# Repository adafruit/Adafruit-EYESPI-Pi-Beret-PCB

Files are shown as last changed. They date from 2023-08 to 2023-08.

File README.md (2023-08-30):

## Adafruit EYESPI Pi Beret PCB

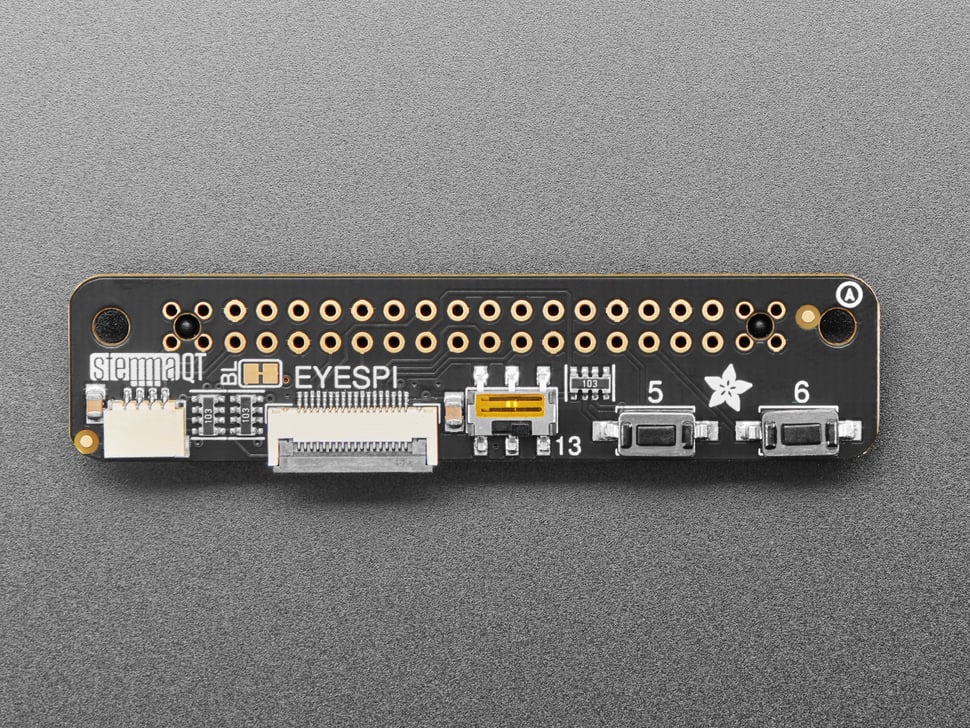
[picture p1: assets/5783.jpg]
<a href="http://www.adafruit.com/products/5783"><br/>
Click here to purchase one from the Adafruit shop</a>

PCB files for the Adafruit EYESPI Pi Beret. 

Format is EagleCAD schematic and board layout
* https://www.adafruit.com/product/5783

### Description

Raspberry Pi's make for handy lil computers, but they're really wonderful when you can connect all sorts of nifty hardware to them: color TFT or E-Ink displays, and sensors are our go-to favorites. Even better is when we make it fast and effortless to wire these up. With this new EYESPI Pi Beret there's no more counting pins or noodling with a breakout board. This slim HAT plugs in and gives you lots of hardware connection options so that many projects become plug-and-play.

Our most recent display breakouts have come with a new feature: an 18-pin "EYE SPI" standard FPC connector with flip-top connector. This is intended to be a sort-of "STEMMA QT for displays" - a way to quickly connect and extend display wiring that uses a lot of SPI pins. In this case we need a lot of SPI and accessory pins, and we want to be able to use long distances, so we go with an 18-pin 0.5mm pitch FPC.

With such a slim and flexible cable, it's easy to have displays anywhere without them physically attached to the Pi like in our PiTFTs. Accessorize with big bold colorful displays or power-sipping E-Ink. 

Don't forget you'll also want an 18-pin EYESPI FPC cable. And of course one of our EYESPI displays too - look for the EYESPI logo on the back to know you've got one that can clip in.

* MOSI/MISO/SCK SPI pins are connected to the default SPI port on the Raspberry Pi
* SDA/SCL I2C pins are connected to the default I2C port on the Pi
* Display CS on Raspberry Pi CE 0
* Display DC on Raspberry Pi GPIO #25
* Display Reset on Raspberry Pi GPIO #27
* Display Busy on Raspberry Pi GPIO #17 (used for E-Inks)
* Display Backlight on Raspberry Pi GPIO #18 (there's a jumper to cut/disable this if you want to use the PWM output for other uses like NeoPixels)
* Touch CS on Raspberry Pi CE 1
* Touch IRQ on Raspberry Pi GPIO #24

The remaining EYESPI pins are not connected, leaving you with plenty of GPIO for other accessory boards.

We also have a Stemma QT connector for the I2C port, to make connecting all sorts of Qwiic/Stemma QT devices super easy, two tactile switches on GPIO #5 and #6 and a slide switch on GPIO #13 which you can use for any sort of interface project or configuration.

Display and EYESPI cable are not included.

### License

Adafruit invests time and resources providing this open source design, please support Adafruit and open-source hardware by purchasing products from [Adafruit](https://www.adafruit.com)!

Designed by Limor Fried/Ladyada for Adafruit Industries.

Creative Commons Attribution/Share-Alike, all text above must be included in any redistribution. 
See license.txt for additional details.

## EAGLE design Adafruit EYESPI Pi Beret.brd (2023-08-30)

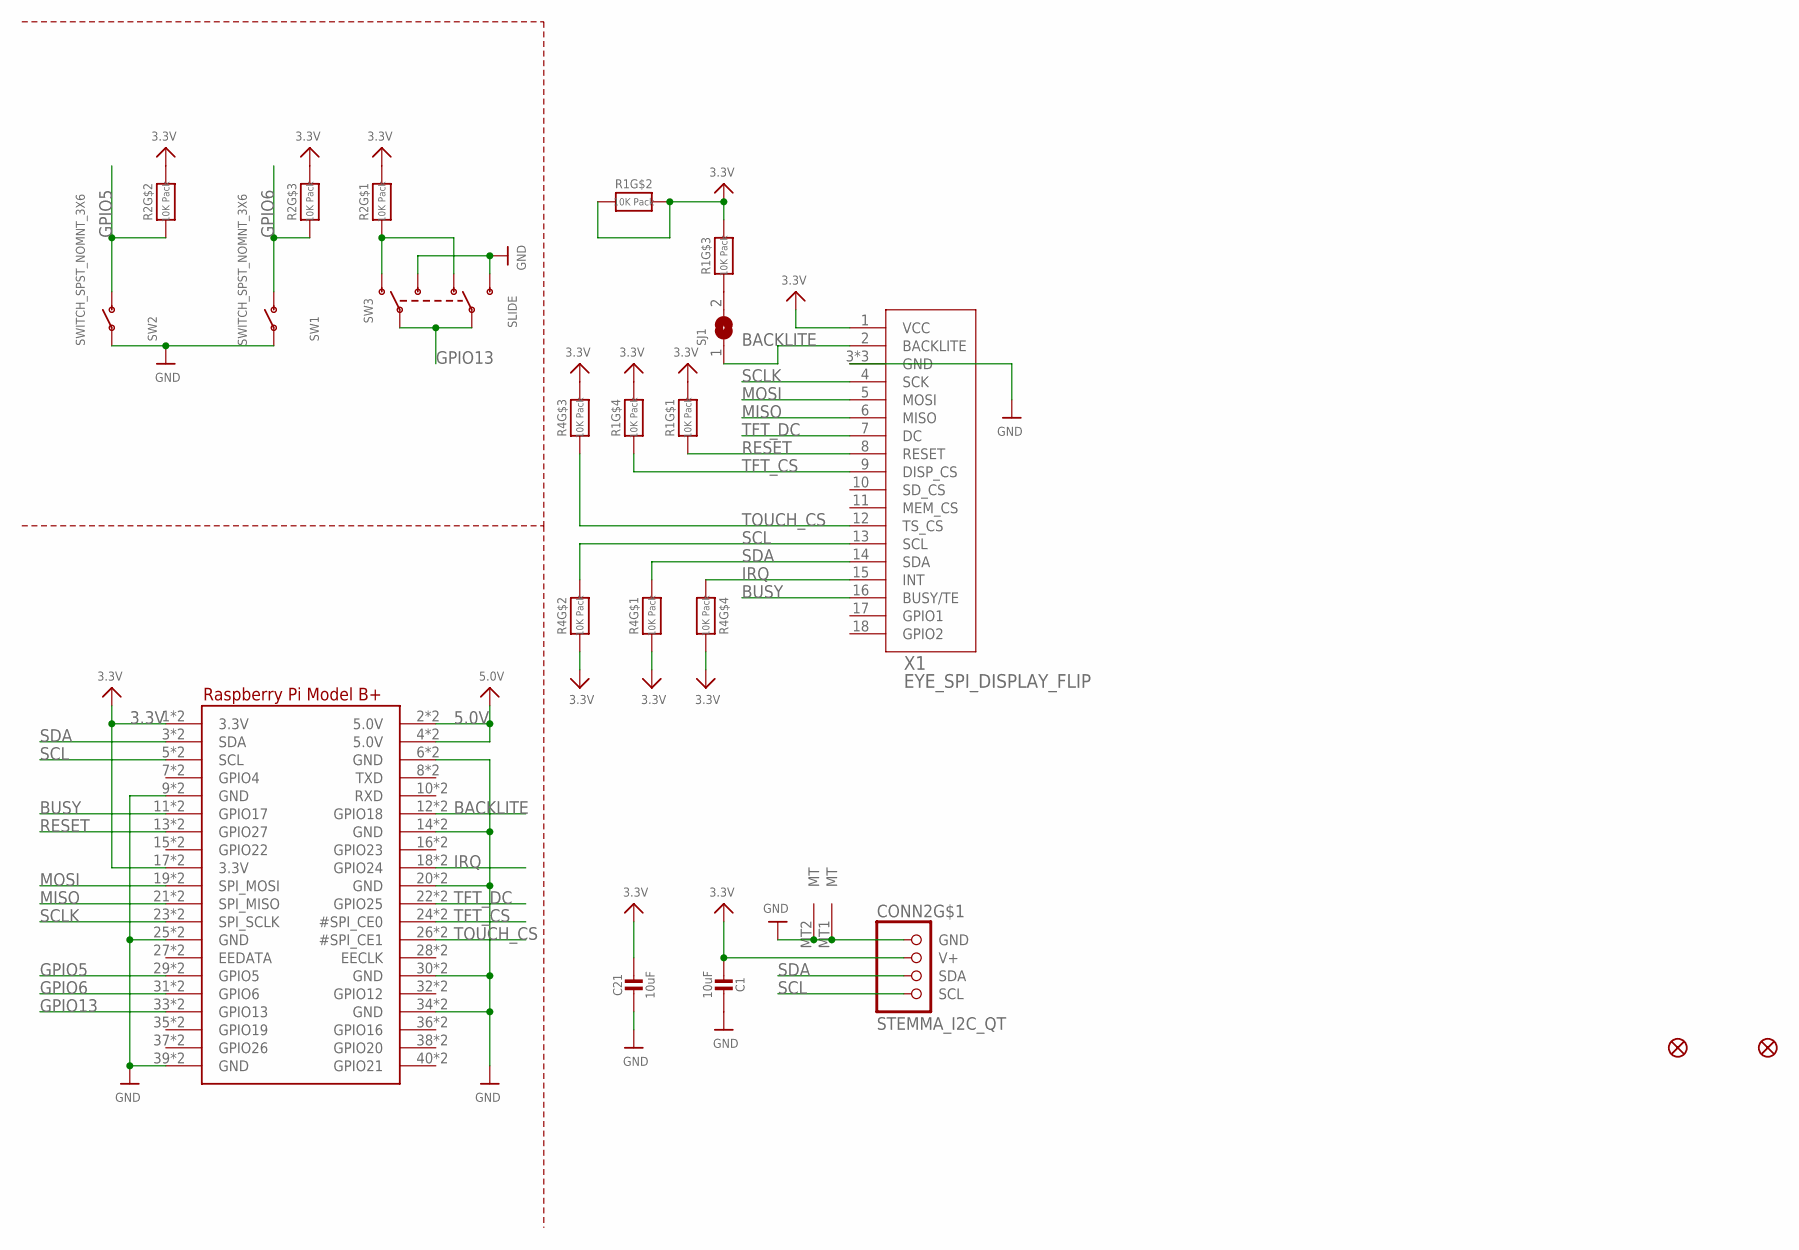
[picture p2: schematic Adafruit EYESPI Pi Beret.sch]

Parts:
C1, C21: 10uF; 0805-NO
CONN2: STEMMA_I2C_QT; JST_SH4
FID1, FID4: FIDUCIAL_1MM
R1, R2, R4: 10K Pack; RESPACK_4X0603
RPI2: RASPBERRYPI_BPLUS_2X20_THMSMT; RASPI_2X20_THMSMT
SJ1: SOLDERJUMPERCLOSED; SOLDERJUMPER_CLOSEDWIRE
SW1, SW2: SWITCH_SPST_NOMNT_3X6; TACTILE_3X6MM
SW3: SLIDE; EG1390
X1: EYE_SPI_DISPLAY_FLIP; EYE_SPI_DISPLAY_BOTCONTACT

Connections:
3.3V: C1.2, C21.1, CONN2.2 (V+), R1.2 (1), R1.5 (2), R1.6 (2), R1.7 (2), R1.8 (2), R2.6 (2), R2.7 (2), R2.8 (2), R4.1, R4.2 (1), R4.5 (2), R4.6 (2), RPI2.1 (3.3V), RPI2.17 (3.3V), RPI2.S1 (3.3V), RPI2.S17 (3.3V), X1.1 (VCC)
5.0V: RPI2.2 (5.0V), RPI2.4 (5.0V), RPI2.S2 (5.0V), RPI2.S4 (5.0V)
BACKLITE: RPI2.12 (GPIO18), RPI2.S12 (GPIO18), SJ1.1, X1.2 (BACKLITE)
BUSY: RPI2.11 (GPIO17), RPI2.S11 (GPIO17), X1.16 (BUSY/TE)
GND: C1.1, C21.2, CONN2.1 (GND), CONN2.MT1 (MT), CONN2.MT2 (MT), RPI2.6 (GND), RPI2.9 (GND), RPI2.14 (GND), RPI2.20 (GND), RPI2.25 (GND), RPI2.30 (GND), RPI2.34 (GND), RPI2.39 (GND), RPI2.S6 (GND), RPI2.S9 (GND), RPI2.S14 (GND), RPI2.S20 (GND), RPI2.S25 (GND), RPI2.S30 (GND), RPI2.S34 (GND), RPI2.S39 (GND), SW1.P$1, SW2.P$1, SW3.S1, SW3.S2, X1.3 (GND), X1.SUPPORT1 (GND), X1.SUPPORT2 (GND)
GPIO5: R2.2 (1), RPI2.29 (GPIO5), RPI2.S29 (GPIO5), SW2.P$2 (S)
GPIO6: R2.3 (1), RPI2.31 (GPIO6), RPI2.S31 (GPIO6), SW1.P$2 (S)
GPIO13: RPI2.33 (GPIO13), RPI2.S33 (GPIO13), SW3.P1, SW3.P2
IRQ: R4.4 (1), RPI2.18 (GPIO24), RPI2.S18 (GPIO24), X1.15 (INT)
MISO: RPI2.21 (SPI_MISO), RPI2.S21 (SPI_MISO), X1.6 (MISO)
MOSI: RPI2.19 (SPI_MOSI), RPI2.S19 (SPI_MOSI), X1.5 (MOSI)
unnamed: R1.3 (1), SJ1.2
unnamed: R2.1, SW3.O1, SW3.O2
RESET: R1.1, RPI2.13 (GPIO27), RPI2.S13 (GPIO27), X1.8 (RESET)
SCL: CONN2.4 (SCL), R4.7 (2), RPI2.5 (SCL), RPI2.S5 (SCL), X1.13 (SCL)
SCLK: RPI2.23 (SPI_SCLK), RPI2.S23 (SPI_SCLK), X1.4 (SCK)
SDA: CONN2.3 (SDA), R4.8 (2), RPI2.3 (SDA), RPI2.S3 (SDA), X1.14 (SDA)
TFT_CS: R1.4 (1), RPI2.24 (#SPI_CE0), RPI2.S24 (#SPI_CE0), X1.9 (DISP_CS)
TFT_DC: RPI2.22 (GPIO25), RPI2.S22 (GPIO25), X1.7 (DC)
TOUCH_CS: R4.3 (1), RPI2.26 (#SPI_CE1), RPI2.S26 (#SPI_CE1), X1.12 (TS_CS)

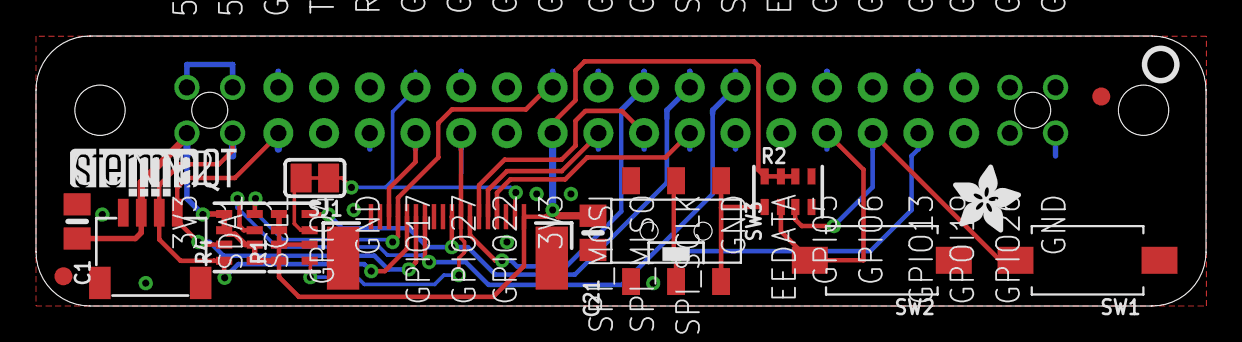
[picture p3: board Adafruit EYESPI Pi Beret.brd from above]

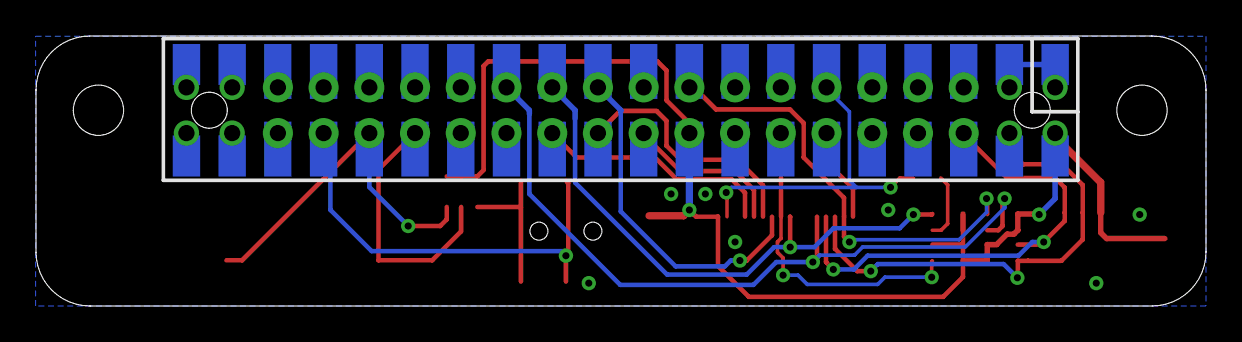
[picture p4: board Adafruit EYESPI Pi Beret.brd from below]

Board: 2 copper layers, 65.0 x 15.0 mm, 24 parts (2 on the bottom side), 20 nets.

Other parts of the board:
PLABEL0: PLABEL0
PLABEL1: PLABEL1
PLABEL2: PLABEL2
PLABEL3: PLABEL3
PLABEL4: PLABEL4
PLABEL5: PLABEL5
PLABEL6: PLABEL6
U$9: PCBFEAT-REV-040
U$24: ADAFRUIT_3.5MM
U$30: STEMMAQT

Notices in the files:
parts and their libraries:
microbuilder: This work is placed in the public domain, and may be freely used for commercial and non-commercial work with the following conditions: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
